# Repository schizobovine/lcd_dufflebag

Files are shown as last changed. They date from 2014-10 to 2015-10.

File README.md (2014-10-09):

lcd_dufflebag
=============

Variation on the common LCD "backpack" design. Instead of using an IO expander or full blown ATMega, however, this design uses an ATTiny84 to drive the LCD, with just enough pins left over to be an I2C slave. Can control RGB LCDs via an optional WS2811 chip or monochrome displays via a simple BJT.

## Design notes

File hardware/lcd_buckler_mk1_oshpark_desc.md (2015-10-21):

Larger 16x2 LCD controller Arduino shield using Yet Another ATTiny84. Reversible. No RGB support.

[https://github.com/schizobovine/lcd_dufflebag](https://github.com/schizobovine/lcd_dufflebag)

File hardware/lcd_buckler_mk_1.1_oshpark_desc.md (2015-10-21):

Revised 8x2 LCD controller Arduino shield using Yet Another ATTiny84. Features solder jumpers to allow host Arduino to program ATTiny84 during development.

[https://github.com/schizobovine/lcd_dufflebag](https://github.com/schizobovine/lcd_dufflebag)

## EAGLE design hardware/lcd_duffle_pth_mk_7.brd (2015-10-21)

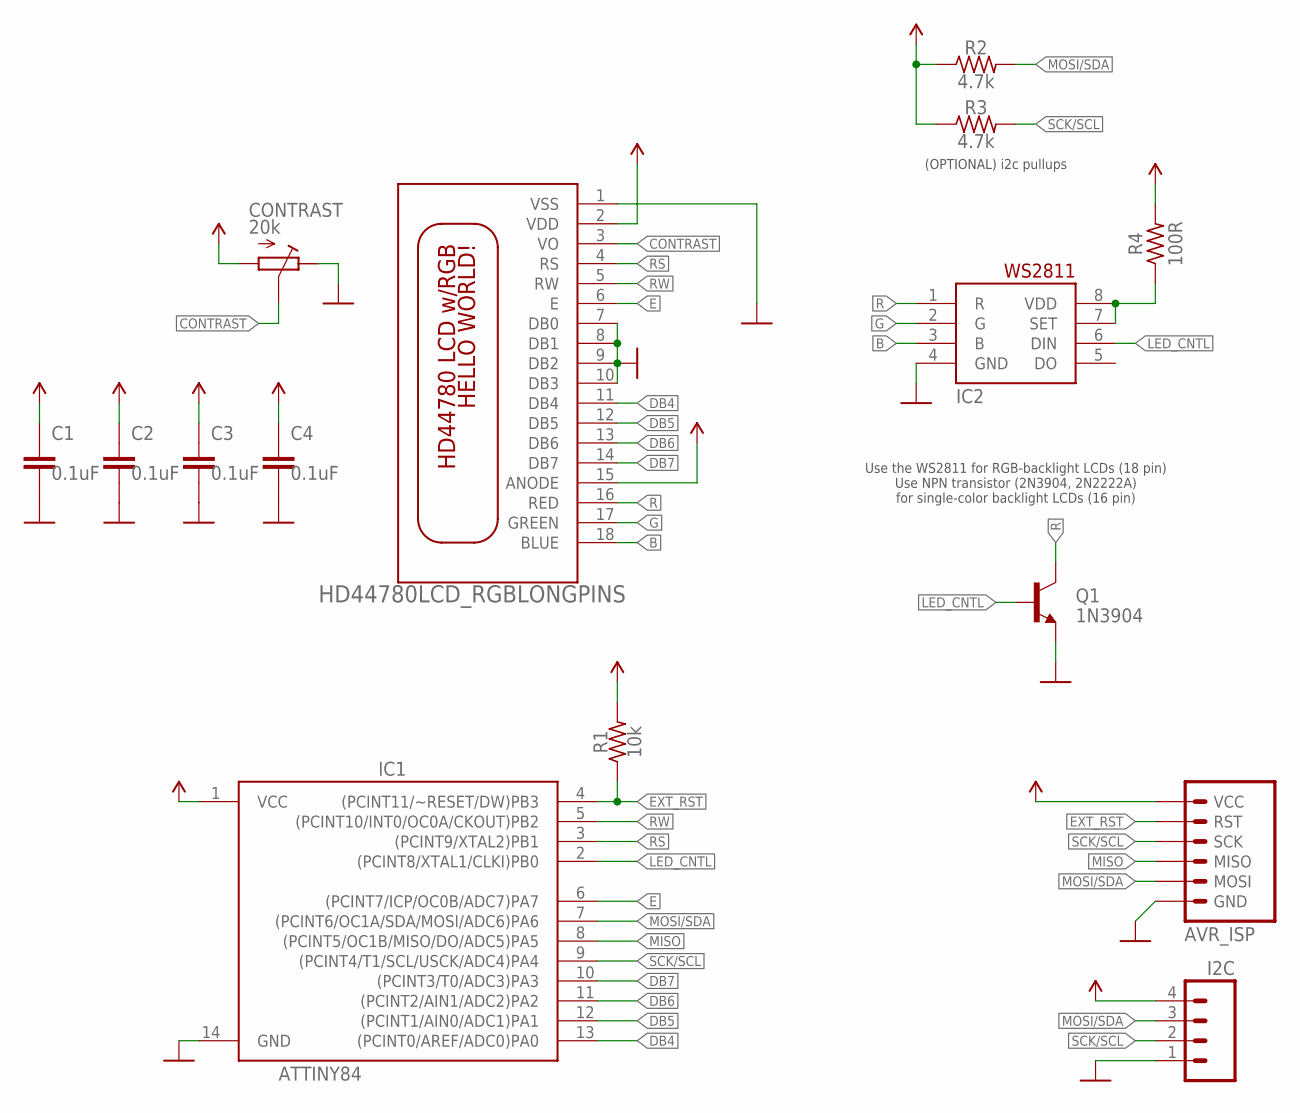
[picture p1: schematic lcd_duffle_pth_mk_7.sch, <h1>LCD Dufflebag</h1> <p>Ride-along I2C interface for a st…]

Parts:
AVR_ISP: AVR_MINI_PROGJST-XH-RA-PTH; AVR_MINI_PROG_JST_XH_RA
C1, C2, C3, C4: 0.1uF; C025-024X044
CONTRAST: 20k; POT-THUMBWHEEL
I2C: M04JST_XH_RA; JST-4-XH-RA-PTH
IC1: ATTINY84; DIL14
IC2: WS2811; SO08-SKINNYPADS
Q1: 1N3904; TO-92-AMMO
R1: 10k; RESISTOR-AXIAL-PTH-5.08MM
R2, R3: 4.7k; RESISTOR-AXIAL-PTH-5.08MM
R4: 100R; RESISTOR-AXIAL-PTH-5.08MM
U$1: HD44780LCD_RGBLONGPINS; LCD1602-RGB-CENTERED

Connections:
5V: AVR_ISP.2 (VCC), C1.2, C2.2, C3.2, C4.2, CONTRAST.1 (A), I2C.4, IC1.1 (VCC), R1.P$2 (2), R2.P$1 (1), R3.P$1 (1), R4.P$2 (2), U$1.2 (VDD), U$1.15 (ANODE)
B: IC2.3 (B), U$1.18 (BLUE)
CONTRAST: CONTRAST.2 (S), CONTRAST.2@1 (S), U$1.3 (VO)
DB4: IC1.13 ((PCINT0/AREF/ADC0)PA0), U$1.11 (DB4)
DB5: IC1.12 ((PCINT1/AIN0/ADC1)PA1), U$1.12 (DB5)
DB6: IC1.11 ((PCINT2/AIN1/ADC2)PA2), U$1.13 (DB6)
DB7: IC1.10 ((PCINT3/T0/ADC3)PA3), U$1.14 (DB7)
E: IC1.6 ((PCINT7/ICP/OC0B/ADC7)PA7), U$1.6 (E)
EXT_RST: AVR_ISP.5 (RST), IC1.4 ((PCINT11/~RESET/DW)PB3), R1.P$1 (1)
G: IC2.2 (G), U$1.17 (GREEN)
GND: AVR_ISP.6 (GND), C1.1, C2.1, C3.1, C4.1, CONTRAST.3 (E), I2C.1, IC1.14 (GND), IC2.4 (GND), Q1.1 (E), U$1.1 (VSS), U$1.7 (DB0), U$1.8 (DB1), U$1.9 (DB2), U$1.10 (DB3)
LED_CNTL: IC1.2 ((PCINT8/XTAL1/CLKI)PB0), IC2.6 (DIN), Q1.2 (B)
MISO: AVR_ISP.1 (MISO), IC1.8 ((PCINT5/OC1B/MISO/DO/ADC5)PA5)
MOSI/SDA: AVR_ISP.4 (MOSI), I2C.3, IC1.7 ((PCINT6/OC1A/SDA/MOSI/ADC6)PA6), R2.P$2 (2)
unnamed: IC2.7 (SET), IC2.8 (VDD), R4.P$1 (1)
R: IC2.1 (R), Q1.3 (C), U$1.16 (RED)
RS: IC1.3 ((PCINT9/XTAL2)PB1), U$1.4 (RS)
RW: IC1.5 ((PCINT10/INT0/OC0A/CKOUT)PB2), U$1.5 (RW)
SCK/SCL: AVR_ISP.3 (SCK), I2C.2, IC1.9 ((PCINT4/T1/SCL/USCK/ADC4)PA4), R3.P$2 (2)

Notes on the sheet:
Use the WS2811 for RGB-backlight LCDs (18 pin) Use NPN transistor (2N3904, 2N2222A) for single-color backlight LCDs (16 pin)
(OPTIONAL) i2c pullups

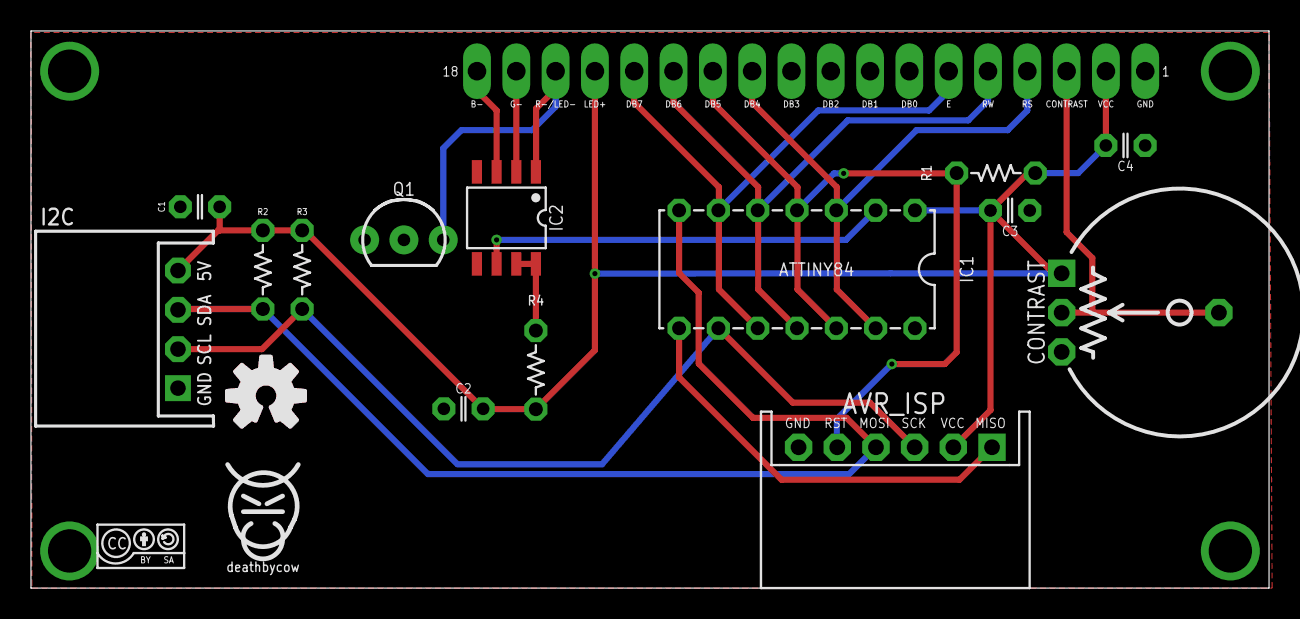
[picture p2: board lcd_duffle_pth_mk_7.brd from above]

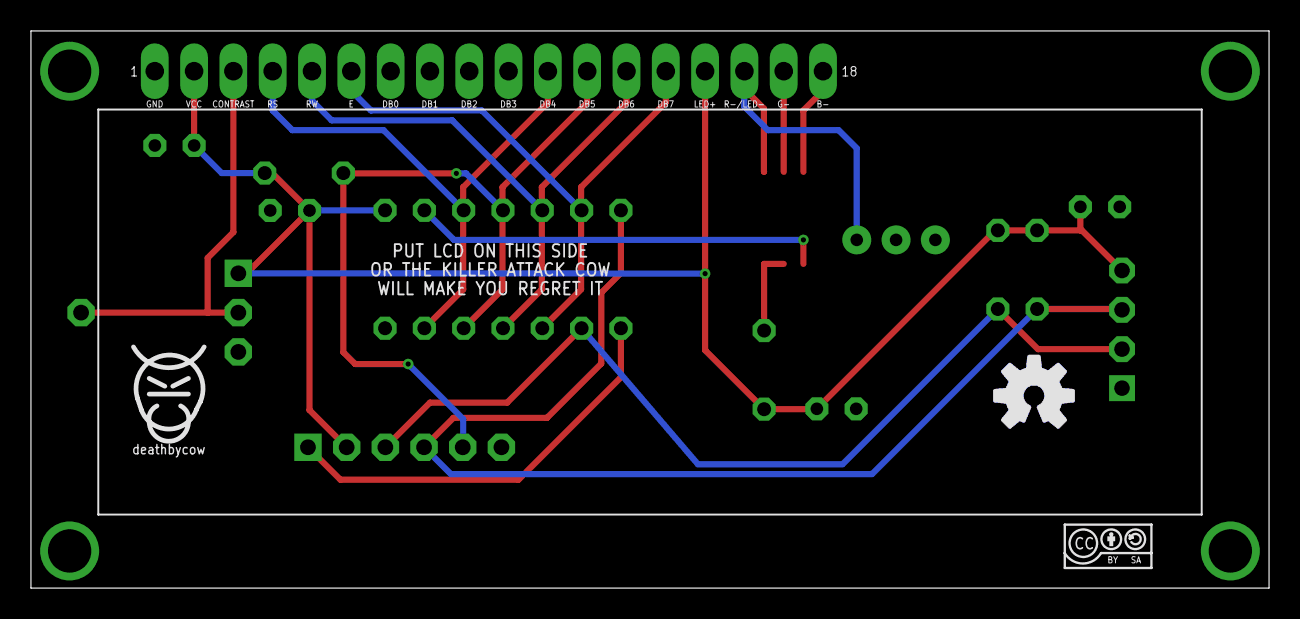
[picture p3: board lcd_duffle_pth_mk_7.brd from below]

Board: 2 copper layers, 80.0 x 36.0 mm, 21 parts (5 on the bottom side), 19 nets.

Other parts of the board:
U$2, U$3: COW_SMALL
U$4, U$6: CC-BY-SA-4.0-NO-URL
U$5: OSHWLOGO_TOP_0.2_A
U$7: OSHWLOGO_BOT_0.2_A

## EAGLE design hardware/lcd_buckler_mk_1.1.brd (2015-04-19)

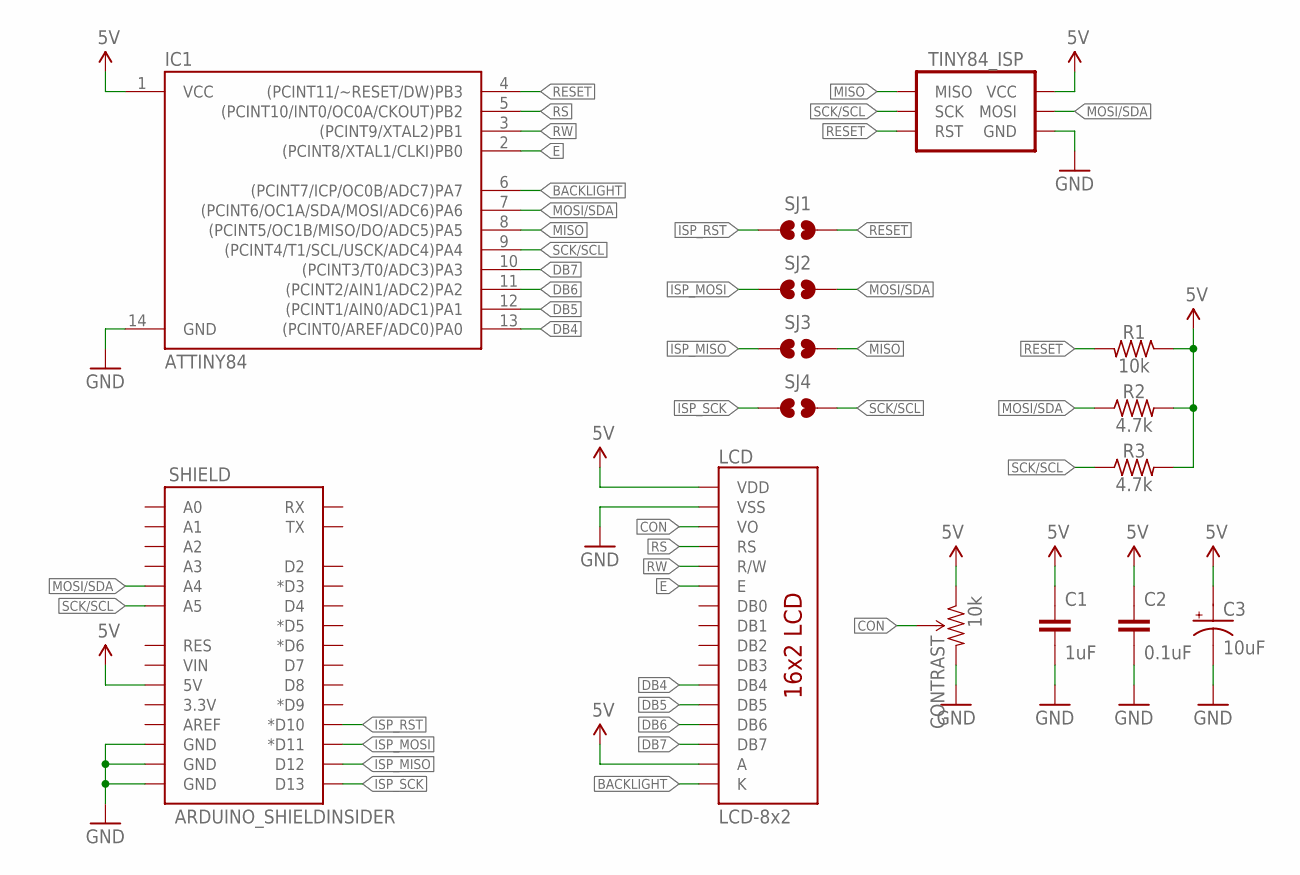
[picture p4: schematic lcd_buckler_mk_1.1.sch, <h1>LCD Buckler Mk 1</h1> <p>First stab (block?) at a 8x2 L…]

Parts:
C1: 1uF; C025-024X044
C2: 0.1uF; C025-024X044
C3: 10uF; E2,5-5
CONTRAST: 10k; TRIM_POT_PTH
IC1: ATTINY84; DIL14
LCD: LCD-8x2; LCD-8X2
R1: 10k; RESISTOR-AXIAL-PTH-7.62MM
R2, R3: 4.7k; RESISTOR-AXIAL-PTH-7.62MM
SHIELD: ARDUINO_SHIELDINSIDER; ARDUINO_SHIELD_NOOUTLINE_INSIDE
SJ1, SJ2, SJ3, SJ4: JUMPER-PAD-2-NO; PAD-JUMPER-2-NO_NO_SILK
TINY84_ISP: AVR_SPI_PRG_6PTH; 2X3

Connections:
5V: C1.1, C2.1, C3.+, CONTRAST.1 (CCW), IC1.1 (VCC), LCD.2 (VDD), LCD.15 (A), R1.P$1 (1), R2.P$2 (2), R3.P$2 (2), SHIELD.5V, TINY84_ISP.2 (VCC)
BACKLIGHT: IC1.6 ((PCINT7/ICP/OC0B/ADC7)PA7), LCD.16 (K)
CON: CONTRAST.2 (WIPER), LCD.3 (VO)
DB4: IC1.13 ((PCINT0/AREF/ADC0)PA0), LCD.11 (DB4)
DB5: IC1.12 ((PCINT1/AIN0/ADC1)PA1), LCD.12 (DB5)
DB6: IC1.11 ((PCINT2/AIN1/ADC2)PA2), LCD.13 (DB6)
DB7: IC1.10 ((PCINT3/T0/ADC3)PA3), LCD.14 (DB7)
E: IC1.2 ((PCINT8/XTAL1/CLKI)PB0), LCD.6 (E)
GND: C1.2, C2.2, C3.-, CONTRAST.3 (CW), IC1.14 (GND), LCD.1 (VSS), SHIELD.GND@0 (GND), SHIELD.GND@1 (GND), SHIELD.GND@2 (GND), TINY84_ISP.6 (GND)
ISP_MISO: SHIELD.D12, SJ3.1
ISP_MOSI: SHIELD.D11 (*D11), SJ2.1
ISP_RST: SHIELD.D10 (*D10), SJ1.1
ISP_SCK: SHIELD.D13, SJ4.1
MISO: IC1.8 ((PCINT5/OC1B/MISO/DO/ADC5)PA5), SJ3.2, TINY84_ISP.1 (MISO)
MOSI/SDA: IC1.7 ((PCINT6/OC1A/SDA/MOSI/ADC6)PA6), R2.P$1 (1), SHIELD.A4, SJ2.2, TINY84_ISP.4 (MOSI)
RESET: IC1.4 ((PCINT11/~RESET/DW)PB3), R1.P$2 (2), SJ1.2, TINY84_ISP.5 (RST)
RS: IC1.5 ((PCINT10/INT0/OC0A/CKOUT)PB2), LCD.4 (RS)
RW: IC1.3 ((PCINT9/XTAL2)PB1), LCD.5 (R/W)
SCK/SCL: IC1.9 ((PCINT4/T1/SCL/USCK/ADC4)PA4), R3.P$1 (1), SHIELD.A5, SJ4.2, TINY84_ISP.3 (SCK)

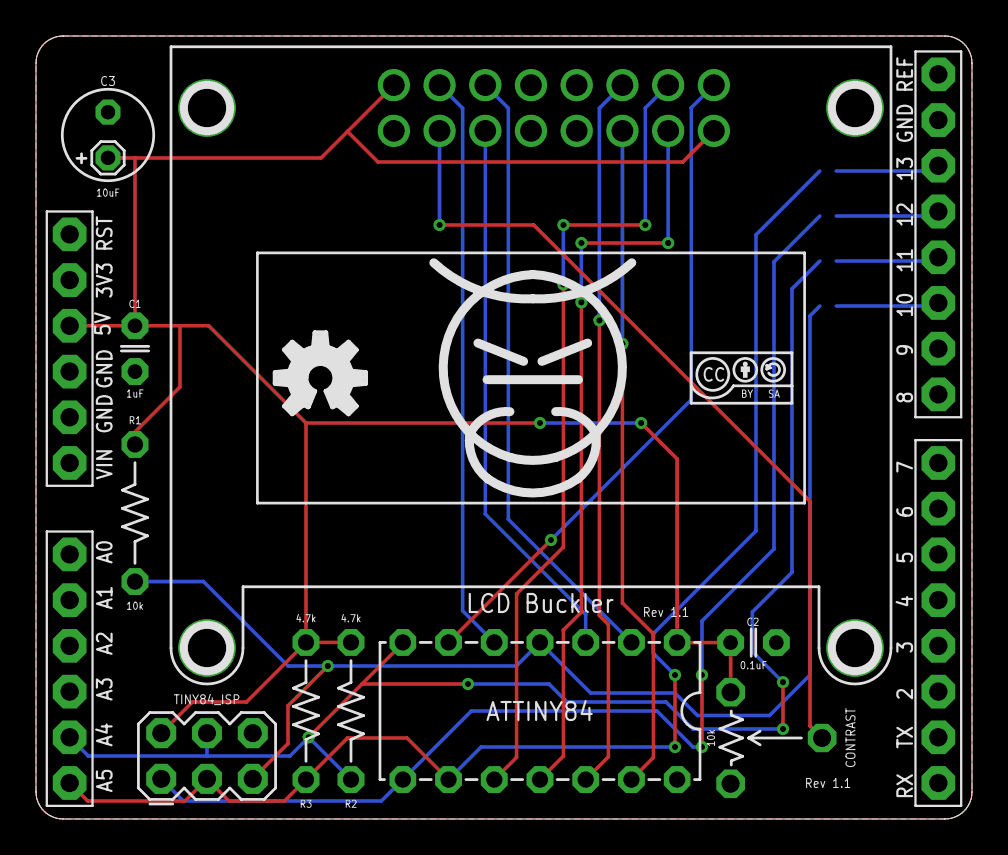
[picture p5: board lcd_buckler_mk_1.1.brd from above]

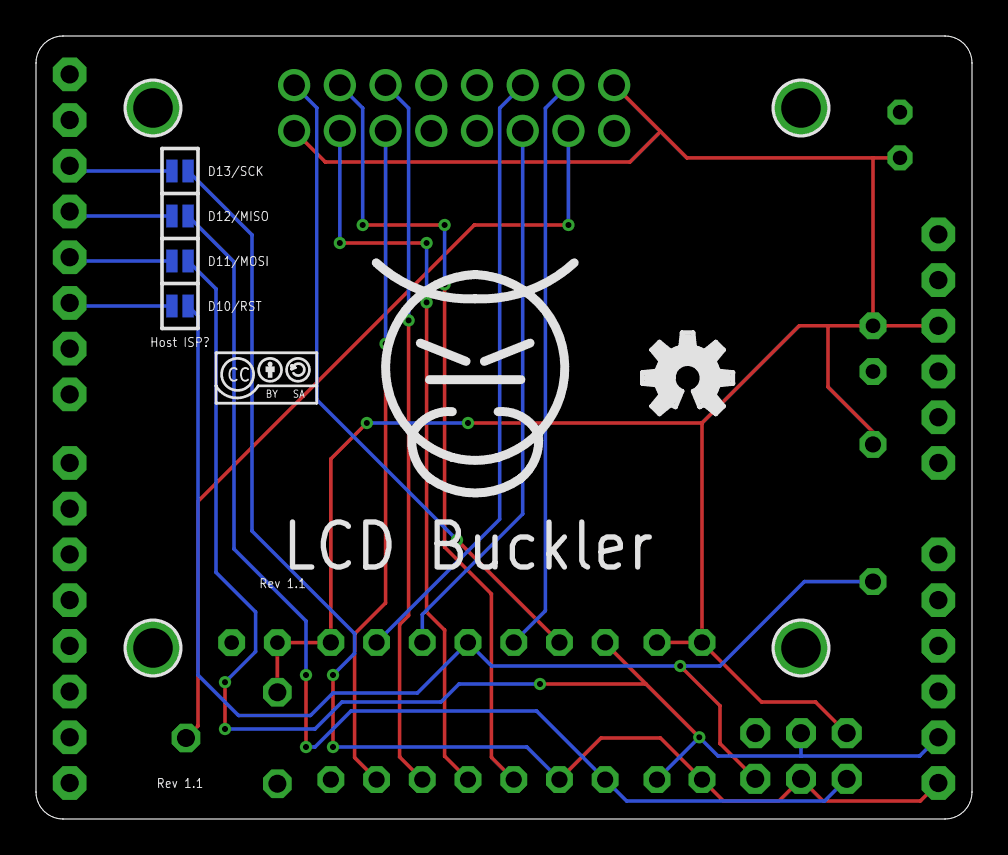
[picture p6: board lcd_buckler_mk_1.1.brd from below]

Board: 2 copper layers, 52.0 x 43.5 mm, 21 parts (7 on the bottom side), 19 nets.

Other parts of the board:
U$1, U$2: COW
U$3, U$4: CC-BY-SA-4.0-NO-URL
U$5, U$6: OSHWLOGO_SILKONLY

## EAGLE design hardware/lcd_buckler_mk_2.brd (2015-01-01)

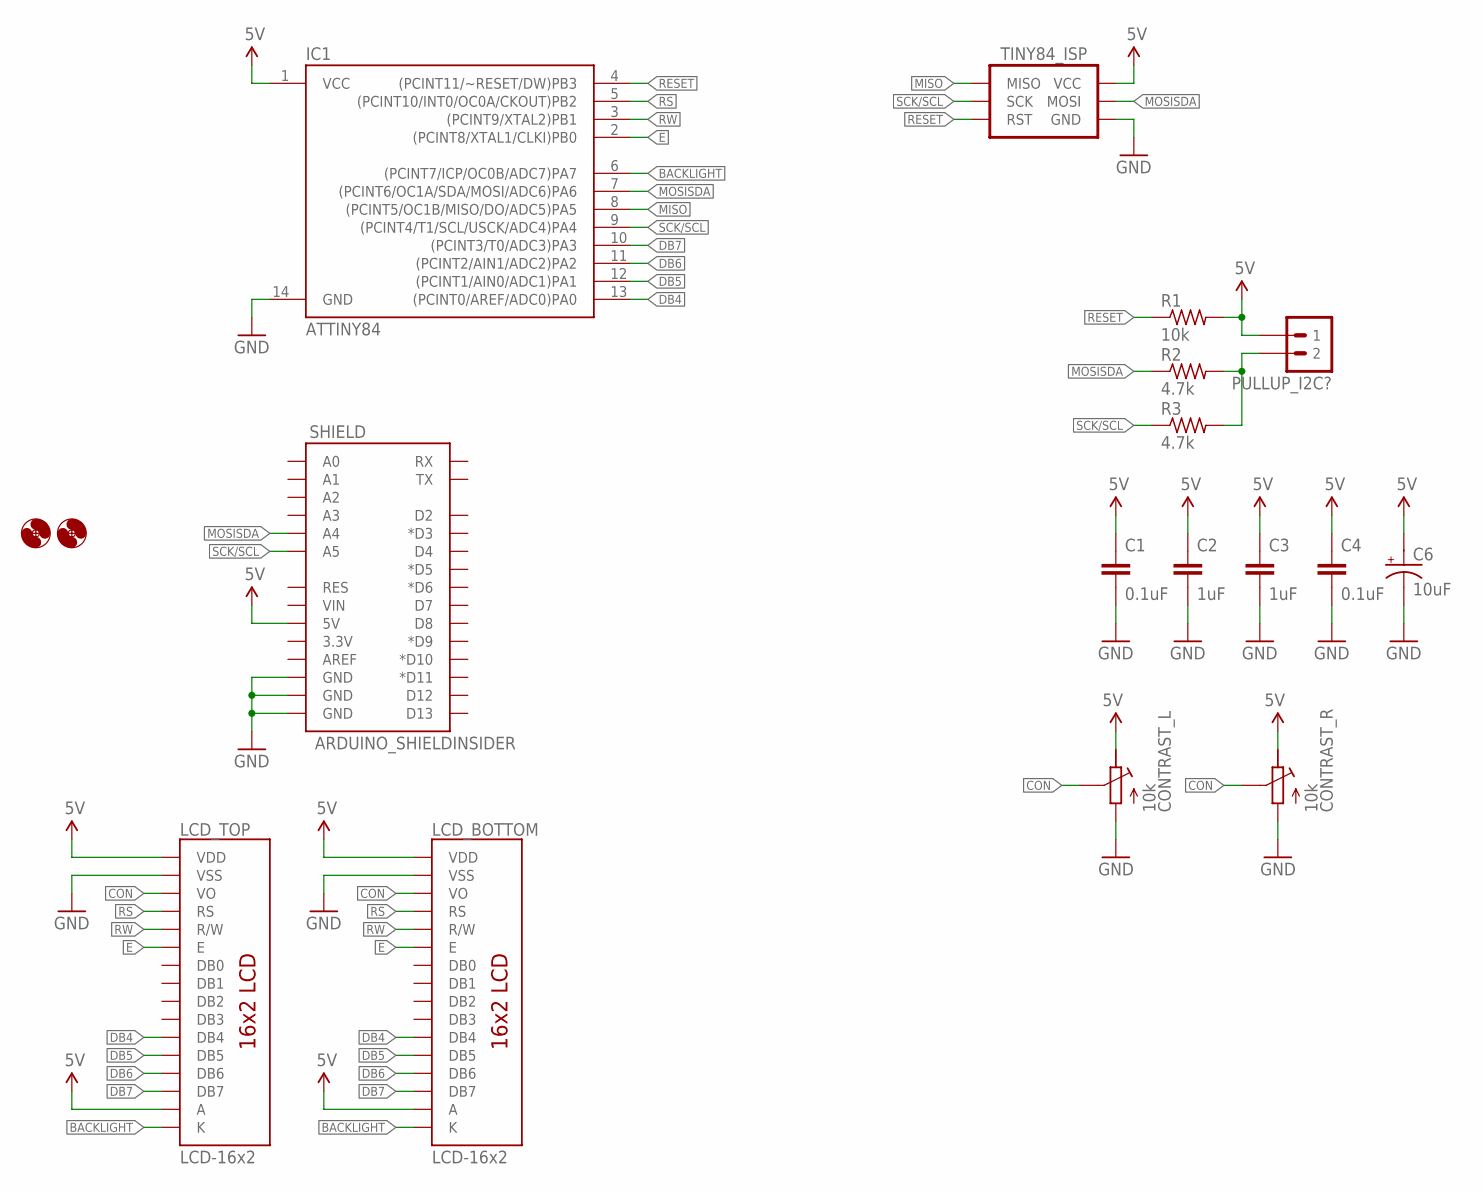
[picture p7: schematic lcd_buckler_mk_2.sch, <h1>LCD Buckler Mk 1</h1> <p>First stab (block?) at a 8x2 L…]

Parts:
C1: 0.1uF; C0805
C2, C3: 1uF; C025-024X044
C4: 0.1uF; C025-024X044
C6: 10uF; E2,5-5
CONTRAST_L: 10k; POT-THUMBWHEEL
CONTRAST_R: 10k; POT-THUMBWHEEL
H1, H2: HOLE#2; HOLE-#2
IC1: ATTINY84; SO14
LCD_BOTTOM: LCD-16x2; LCD-16X2-PINS-ONLY
LCD_TOP: LCD-16x2; LCD-16X2-PINS-ONLY
PULLUP_I2C?: M02PTH; 1X02
R1: 10k; R0805
R2, R3: 4.7k; RESISTOR-AXIAL-PTH-7.68MM
SHIELD: ARDUINO_SHIELDINSIDER; ARDUINO_SHIELD_NOOUTLINE_INSIDE
TINY84_ISP: AVR_SPI_PRG_6PTH; 2X3

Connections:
5V: C1.1, C2.1, C3.1, C4.1, C6.+, CONTRAST_L.3 (E), CONTRAST_R.3 (E), IC1.1 (VCC), LCD_BOTTOM.2 (VDD), LCD_BOTTOM.15 (A), LCD_TOP.2 (VDD), LCD_TOP.15 (A), PULLUP_I2C?.1, R1.2, SHIELD.5V, TINY84_ISP.2 (VCC)
BACKLIGHT: IC1.6 ((PCINT7/ICP/OC0B/ADC7)PA7), LCD_BOTTOM.16 (K), LCD_TOP.16 (K)
CON: CONTRAST_L.2 (S), CONTRAST_L.2@1 (S), CONTRAST_R.2 (S), CONTRAST_R.2@1 (S), LCD_BOTTOM.3 (VO), LCD_TOP.3 (VO)
DB4: IC1.13 ((PCINT0/AREF/ADC0)PA0), LCD_BOTTOM.11 (DB4), LCD_TOP.11 (DB4)
DB5: IC1.12 ((PCINT1/AIN0/ADC1)PA1), LCD_BOTTOM.12 (DB5), LCD_TOP.12 (DB5)
DB6: IC1.11 ((PCINT2/AIN1/ADC2)PA2), LCD_BOTTOM.13 (DB6), LCD_TOP.13 (DB6)
DB7: IC1.10 ((PCINT3/T0/ADC3)PA3), LCD_BOTTOM.14 (DB7), LCD_TOP.14 (DB7)
E: IC1.2 ((PCINT8/XTAL1/CLKI)PB0), LCD_BOTTOM.6 (E), LCD_TOP.6 (E)
GND: C1.2, C2.2, C3.2, C4.2, C6.-, CONTRAST_L.1 (A), CONTRAST_R.1 (A), IC1.14 (GND), LCD_BOTTOM.1 (VSS), LCD_TOP.1 (VSS), SHIELD.GND@0 (GND), SHIELD.GND@1 (GND), SHIELD.GND@2 (GND), TINY84_ISP.6 (GND)
MISO: IC1.8 ((PCINT5/OC1B/MISO/DO/ADC5)PA5), TINY84_ISP.1 (MISO)
MOSISDA: IC1.7 ((PCINT6/OC1A/SDA/MOSI/ADC6)PA6), R2.P$1 (1), SHIELD.A4, TINY84_ISP.4 (MOSI)
unnamed: PULLUP_I2C?.2, R2.P$2 (2), R3.P$2 (2)
RESET: IC1.4 ((PCINT11/~RESET/DW)PB3), R1.1, TINY84_ISP.5 (RST)
RS: IC1.5 ((PCINT10/INT0/OC0A/CKOUT)PB2), LCD_BOTTOM.4 (RS), LCD_TOP.4 (RS)
RW: IC1.3 ((PCINT9/XTAL2)PB1), LCD_BOTTOM.5 (R/W), LCD_TOP.5 (R/W)
SCK/SCL: IC1.9 ((PCINT4/T1/SCL/USCK/ADC4)PA4), R3.P$1 (1), SHIELD.A5, TINY84_ISP.3 (SCK)

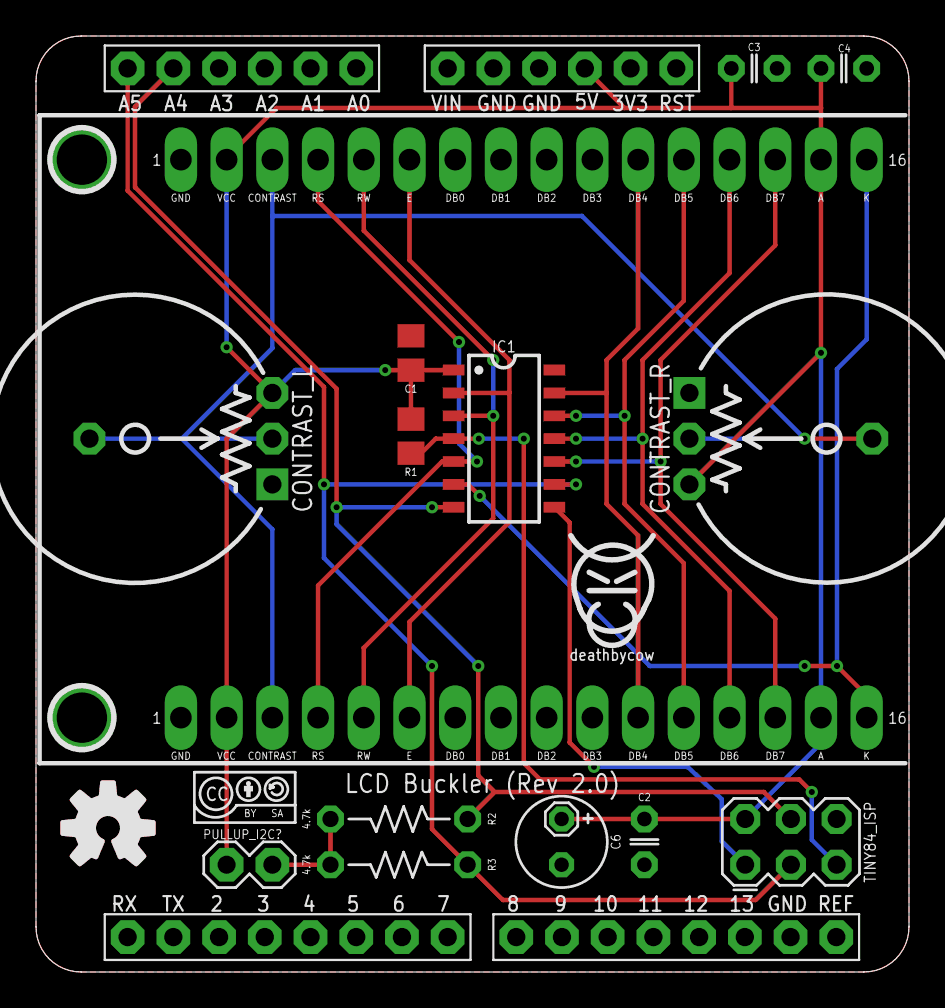
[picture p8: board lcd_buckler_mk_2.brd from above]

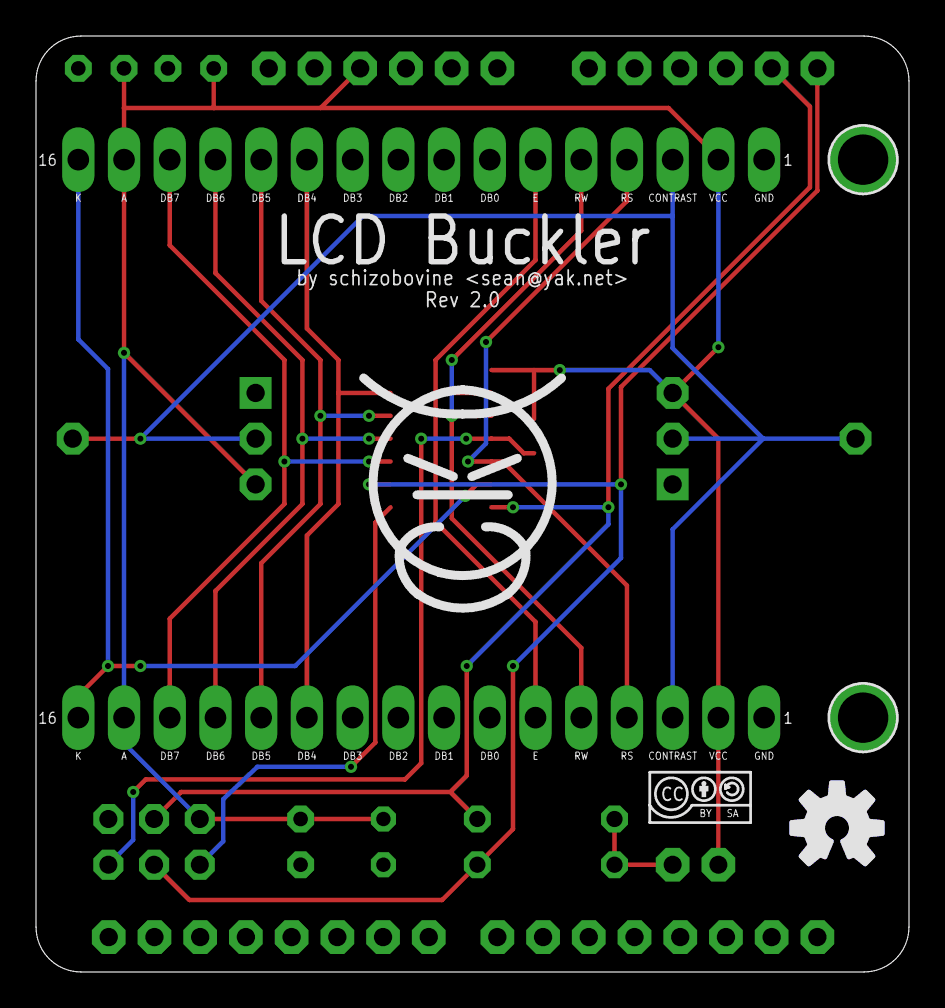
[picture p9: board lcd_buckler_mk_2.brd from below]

Board: 2 copper layers, 48.5 x 52.0 mm, 24 parts (2 on the bottom side), 16 nets.

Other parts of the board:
U$1: COW
U$2: COW_SMALL
U$3, U$4: CC-BY-SA-4.0-NO-URL
U$5: OSHWLOGO_TOP_0.2_A
U$6: OSHWLOGO_BOT_0.2_A

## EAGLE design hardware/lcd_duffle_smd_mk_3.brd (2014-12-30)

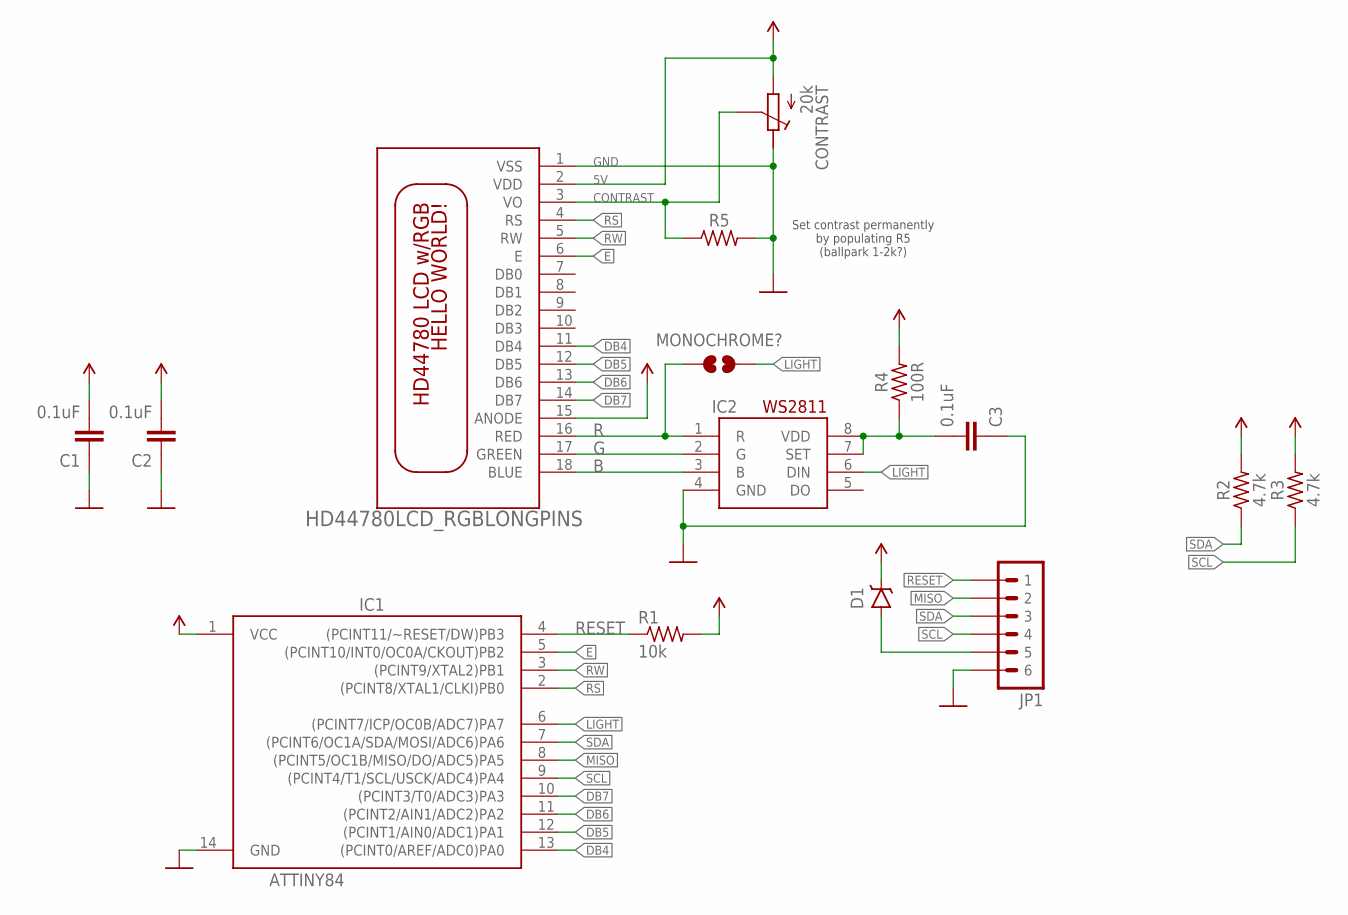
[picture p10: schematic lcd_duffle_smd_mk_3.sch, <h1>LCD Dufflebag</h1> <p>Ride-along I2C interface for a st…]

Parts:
C1, C2, C3: 0.1uF; C0805
CONTRAST: 20k; RTRIM3314Z-SIDE
D1: MBRA140; SMA-DIODE
IC1: ATTINY84; SO14
IC2: WS2811; SO08-SKINNYPADS
JP1: M06SMD; 1X06-SMD
MONOCHROME?: JUMPER-PAD-2-NOYES_SILK; PAD-JUMPER-2-NO_YES_SILK
R1: 10k; R0805
R2, R3: 4.7k; R0805
R4: 100R; R0805
R5: RESISTORR0805; R0805
U$1: HD44780LCD_RGBLONGPINS; LCD1602-RGB-CENTERED

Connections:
5V: C1.2, C2.2, CONTRAST.1 (A), D1.C, IC1.1 (VCC), R1.2, R2.2, R3.2, R4.2, U$1.2 (VDD), U$1.15 (ANODE)
B: IC2.3 (B), U$1.18 (BLUE)
CONTRAST: CONTRAST.2 (S), R5.1, U$1.3 (VO)
DB4: IC1.13 ((PCINT0/AREF/ADC0)PA0), U$1.11 (DB4)
DB5: IC1.12 ((PCINT1/AIN0/ADC1)PA1), U$1.12 (DB5)
DB6: IC1.11 ((PCINT2/AIN1/ADC2)PA2), U$1.13 (DB6)
DB7: IC1.10 ((PCINT3/T0/ADC3)PA3), U$1.14 (DB7)
E: IC1.5 ((PCINT10/INT0/OC0A/CKOUT)PB2), U$1.6 (E)
G: IC2.2 (G), U$1.17 (GREEN)
GND: C1.1, C2.1, C3.1, CONTRAST.3 (E), IC1.14 (GND), IC2.4 (GND), JP1.6, R5.2, U$1.1 (VSS)
LIGHT: IC1.6 ((PCINT7/ICP/OC0B/ADC7)PA7), IC2.6 (DIN), MONOCHROME?.2
MISO: IC1.8 ((PCINT5/OC1B/MISO/DO/ADC5)PA5), JP1.2
unnamed: D1.A, JP1.5
unnamed: C3.2, IC2.7 (SET), IC2.8 (VDD), R4.1
R: IC2.1 (R), MONOCHROME?.1, U$1.16 (RED)
RESET: IC1.4 ((PCINT11/~RESET/DW)PB3), JP1.1, R1.1
RS: IC1.2 ((PCINT8/XTAL1/CLKI)PB0), U$1.4 (RS)
RW: IC1.3 ((PCINT9/XTAL2)PB1), U$1.5 (RW)
SCL: IC1.9 ((PCINT4/T1/SCL/USCK/ADC4)PA4), JP1.4, R3.1
SDA: IC1.7 ((PCINT6/OC1A/SDA/MOSI/ADC6)PA6), JP1.3, R2.1

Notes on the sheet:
Set contrast permanently by populating R5 (ballpark 1-2k?)

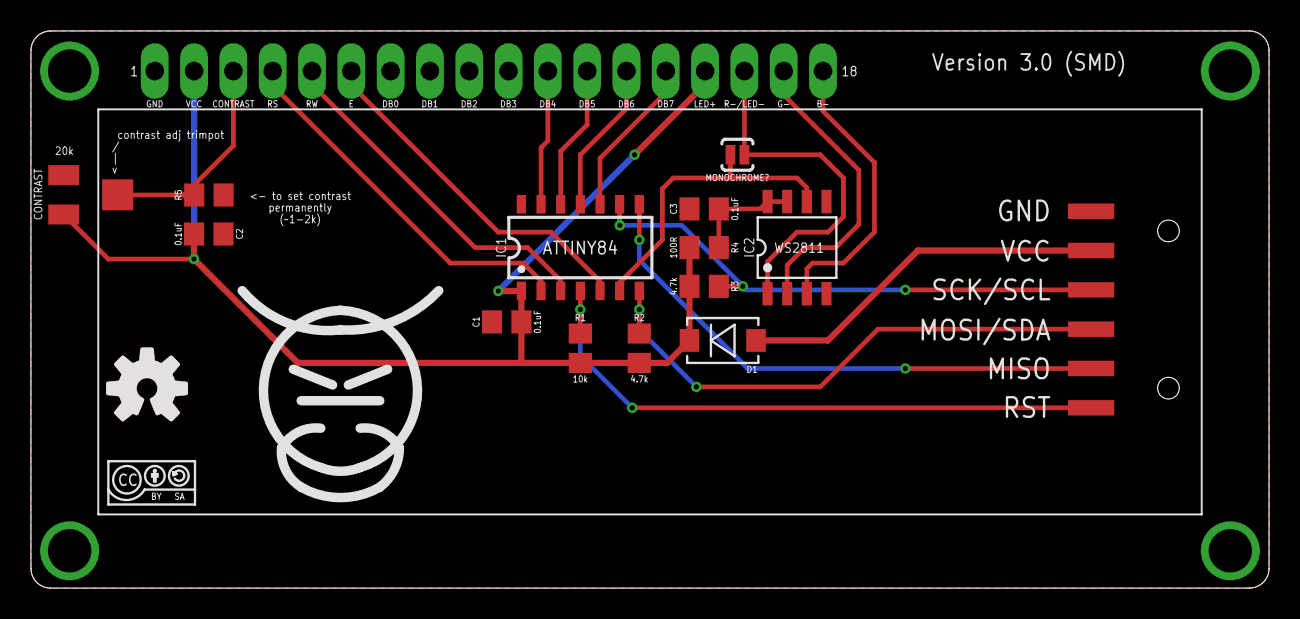
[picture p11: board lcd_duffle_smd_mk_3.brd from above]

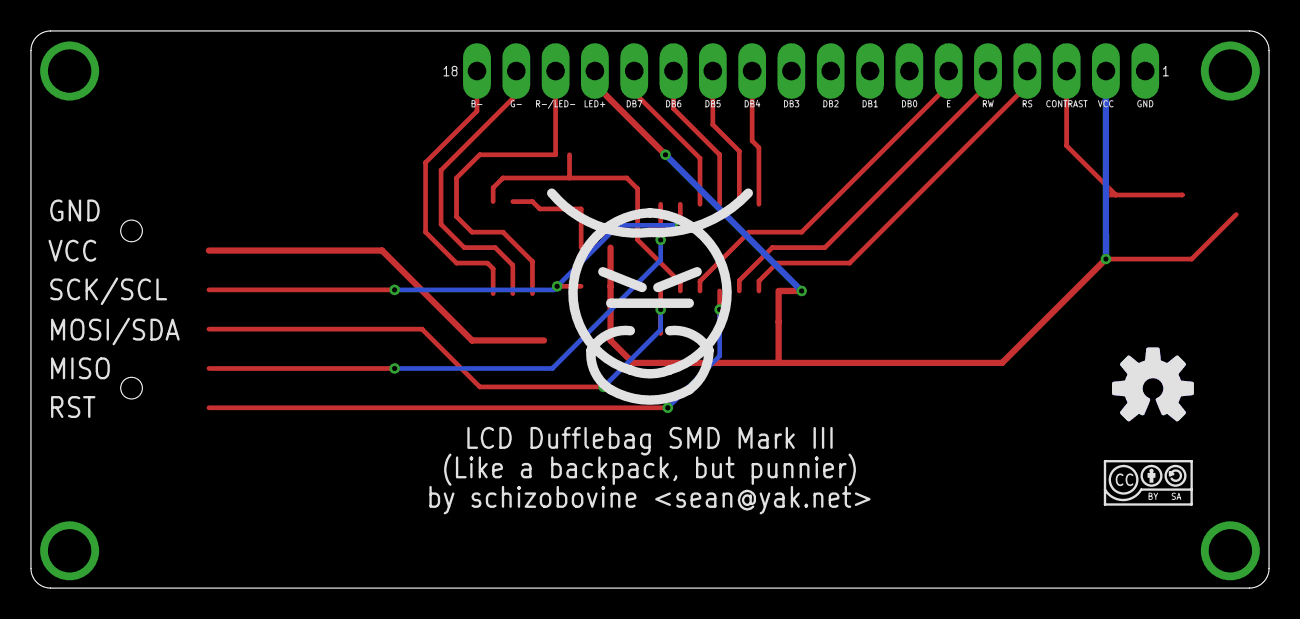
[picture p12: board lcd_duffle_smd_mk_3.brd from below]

Board: 2 copper layers, 80.0 x 36.0 mm, 21 parts (2 on the bottom side), 20 nets.

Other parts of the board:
U$2, U$3: COW
U$4, U$5: CC-BY-SA-4.0-NO-URL
U$6: OSHWLOGO_TOP_0.2_A
U$7: OSHWLOGO_BOT_0.2_A

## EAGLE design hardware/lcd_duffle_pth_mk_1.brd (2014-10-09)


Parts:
ATTINY84: ATTINY84ATTINY84-20PU; DIL14
C1, C2, C3, C4: 0.1uF; C025-024X044
CONTRAST: TRIMPOT3362U-2; 3362U-2
ICSP: AVR_SPI_PRG_6PTH; 2X3
JP1: I2C; MOLEX-1X4
JP2: I2C; 1X04-BIG
Q1: 2N3904; TO-92-AMMO
R1: 10k; AXIAL-PTH-5.08MM
R3: 33R; AXIAL-PTH-5.08MM
R4: 100R; AXIAL-PTH-5.08MM
U$1: HD44780LCD_RGBLONGPINS; LCD1602-RGB
WS2811: WS2811-SOP8; SO08-SKINNYPADS

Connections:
5V: ATTINY84.1 (VCC), C2.2, C3.2, C4.2, CONTRAST.3 (CW), ICSP.2, JP1.4, JP2.4, Q1.3 (C), R1.P$1 (2), R4.P$1 (2), U$1.2 (VDD)
B: U$1.18 (BLUE), WS2811.3 (B)
BL_EN: ATTINY84.8 ((PCINT5/OC1B/MISO/DO/ADC5)PA5), ICSP.1, Q1.2 (B)
CONTRAST: CONTRAST.2 (WIPER), U$1.3 (VO)
DB4: ATTINY84.10 ((PCINT3/T0/ADC3)PA3), U$1.11 (DB4)
DB5: ATTINY84.11 ((PCINT2/AIN1/ADC2)PA2), U$1.12 (DB5)
DB6: ATTINY84.12 ((PCINT1/AIN0/ADC1)PA1), U$1.13 (DB6)
DB7: ATTINY84.13 ((PCINT0/AREF/ADC0)PA0), U$1.14 (DB7)
E: ATTINY84.6 ((PCINT7/ICP/OC0B/ADC7)PA7), U$1.6 (E)
G: U$1.17 (GREEN), WS2811.2 (G)
GND: ATTINY84.14 (GND), C2.1, C3.1, C4.1, CONTRAST.1 (CCW), ICSP.6, JP1.1, JP2.1, U$1.1 (VSS), WS2811.4 (GND)
LED_CNTL: ATTINY84.5 ((PCINT10/INT0/OC0A/CKOUT)PB2), R3.P$1 (2)
unnamed: R3.P$2 (1), WS2811.6 (DIN)
unnamed: R4.P$2 (1), WS2811.7 (SET), WS2811.8 (VDD)
unnamed: C1.1, ICSP.5
unnamed: Q1.1 (E), U$1.15 (ANODE)
R: U$1.16 (RED), WS2811.1 (R)
RS: ATTINY84.3 ((PCINT9/XTAL2)PB1), U$1.4 (RS)
RST: ATTINY84.4 ((PCINT11/~RESET/DW)PB3), C1.2, R1.P$2 (1)
RW: ATTINY84.2 ((PCINT8/XTAL1/CLKI)PB0), U$1.5 (RW)
SCL: ATTINY84.9 ((PCINT4/T1/SCL/USCK/ADC4)PA4), ICSP.3, JP1.2, JP2.2
SDA: ATTINY84.7 ((PCINT6/OC1A/SDA/MOSI/ADC6)PA6), ICSP.4, JP1.3, JP2.3


Board: 2 copper layers, 80.0 x 36.2 mm, 15 parts (1 on the bottom side), 22 nets.

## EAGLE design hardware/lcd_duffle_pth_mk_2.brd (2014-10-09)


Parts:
ATTINY84: ATTINY84; SO14
C1, C2, C3, C4: 0.1uF; C025-024X044
CONTRAST: POTENTIOMETERTHUMBWHEEL-16MM; POT-THUMBWHEEL
ICSP: M03X2POGO_PINS; 2X3_POGO
JP1: I2C; 1X04-2.5MM_JST_XH_RA
R1: 10k; RESISTOR-AXIAL-PTH-5.08MM
R3: 33R; RESISTOR-AXIAL-PTH-5.08MM
R4: 100R; RESISTOR-AXIAL-PTH-5.08MM
U$1: HD44780LCD_RGBLONGPINS; LCD1602-RGB-CENTERED
WS2811: WS2811-SOP8; SO08-SKINNYPADS

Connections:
5V: ATTINY84.1 (VCC), C2.2, C3.2, C4.2, CONTRAST.1 (A), ICSP.P$2 (2), JP1.4, R1.P$2 (2), R4.P$2 (2), U$1.2 (VDD), U$1.15 (ANODE)
B: U$1.18 (BLUE), WS2811.3 (B)
CONTRAST: CONTRAST.2 (S), CONTRAST.2@1 (S), U$1.3 (VO)
DB4: ATTINY84.13 ((PCINT0/AREF/ADC0)PA0), U$1.11 (DB4)
DB5: ATTINY84.12 ((PCINT1/AIN0/ADC1)PA1), U$1.12 (DB5)
DB6: ATTINY84.11 ((PCINT2/AIN1/ADC2)PA2), U$1.13 (DB6)
DB7: ATTINY84.10 ((PCINT3/T0/ADC3)PA3), U$1.14 (DB7)
E: ATTINY84.8 ((PCINT5/OC1B/MISO/DO/ADC5)PA5), ICSP.P$1 (1), U$1.6 (E)
G: U$1.17 (GREEN), WS2811.2 (G)
GND: ATTINY84.14 (GND), C2.1, C3.1, C4.1, CONTRAST.3 (E), ICSP.P$6 (6), JP1.1, U$1.1 (VSS), U$1.7 (DB0), U$1.8 (DB1), U$1.9 (DB2), U$1.10 (DB3), WS2811.4 (GND)
LED_CNTL: ATTINY84.5 ((PCINT10/INT0/OC0A/CKOUT)PB2), R3.P$2 (2)
unnamed: R3.P$1 (1), WS2811.6 (DIN)
unnamed: R4.P$1 (1), WS2811.7 (SET), WS2811.8 (VDD)
unnamed: C1.1, ICSP.P$5 (5)
R: U$1.16 (RED), WS2811.1 (R)
RS: ATTINY84.3 ((PCINT9/XTAL2)PB1), U$1.4 (RS)
RST: ATTINY84.4 ((PCINT11/~RESET/DW)PB3), C1.2, R1.P$1 (1)
RW: ATTINY84.6 ((PCINT7/ICP/OC0B/ADC7)PA7), U$1.5 (RW)
SCL: ATTINY84.9 ((PCINT4/T1/SCL/USCK/ADC4)PA4), ICSP.P$3 (3), JP1.2
SDA: ATTINY84.7 ((PCINT6/OC1A/SDA/MOSI/ADC6)PA6), ICSP.P$4 (4), JP1.3

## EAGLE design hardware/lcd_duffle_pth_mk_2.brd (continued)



Board: 2 copper layers, 80.0 x 36.0 mm, 17 parts (4 on the bottom side), 20 nets.

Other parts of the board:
U$2, U$3: COW_SMALL
U$5: OSHWLOGO_TOP_0.2_A
U$7: OSHWLOGO_BOT_0.2_A

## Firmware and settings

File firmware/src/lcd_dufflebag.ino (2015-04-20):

/*
 * lcd_dufflebag.h
 */

#include <Arduino.h>
#include <EEPROM.h>
#include <LiquidCrystal.h>
#include <SoftwareSerial.h>
#include "lcd_dufflebag.h"

byte brightness = 0x7f;

SoftwareSerial nouart(RX, TX);
LiquidCrystal lcd = LiquidCrystal(RS, RW, E, DB4, DB5, DB6, DB7);

void display_setup() {

  pinMode(BACKLIGHT, OUTPUT);
  analogWrite(BACKLIGHT, brightness);

  lcd.begin(COLS, ROWS);
  lcd.print("DICKBUTT");
  delay(300);
  lcd.clear();

}

void cmd_clear() {
  lcd.clear();
}

void cmd_home() {
  lcd.home();
}

void cmd_reset() {
  display_setup();
}

void setup() {

  display_setup();

  nouart.begin(9600);

}

void loop() {
  
  // Poll for new data
  if (nouart.available()) {
    byte c = nouart.read();

    // Check for and handle magical command bytes. Should make this a proper
    // state machine.
    if (c >= UART_CMD_MIN) {
      switch (c) {
        case UART_CMD_HOME:
          break;
        case UART_CMD_CLEAR:
          break;
        case UART_CMD_RESET:
          break;
        default:
          break;
      }

    // Default is to write a character to the display
    } else {
      lcd.write(c);
    }

  }

}

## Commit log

2014-10-09 initial commit of work so far
    [lcd_duffle_pth_mk_1.brd, lcd_duffle_pth_mk_1.sch, lcd_duffle_pth_mk_2.brd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]
2014-10-09 mark 5: more bugfixes
    [lcd_duffle_pth_mk_5.brd, lcd_duffle_pth_mk_5.sch]
2014-10-09 revised board to add i2c pullups, relayout to reduce vias since most were due to poor planning, and remove cap from external reset line as it shouldn't be needed according to atmel's docs
    [lcd_duffle_pth_mk_5.brd, lcd_duffle_pth_mk_5.sch]
2014-10-11 prelim version using attiny861
    [lcd_duffle_pth_mk_6.sch]
2014-12-15 updating libs
    [lcd_duffle_smd_mk_2.brd, lcd_duffle_smd_mk_2.sch]
2014-12-15 firmware isn't working, but committing anyway; new smd version that will be on the LCD side to minimize exposed area
    [lcd_duffle_smd_mk_3.brd, lcd_duffle_smd_mk_3.sch]
2014-12-16 ready for the fab
    [lcd_duffle_smd_mk_3.brd, lcd_duffle_smd_mk_3.sch]
2014-12-16 minor tweaks to stop overlapping silkscreen
    [lcd_duffle_smd_mk_3.brd, lcd_duffle_smd_mk_3.sch]
2014-12-16 adding description to board to see if oshpark picks it up
    [lcd_duffle_smd_mk_3.brd]
2014-12-30 LCD i2c interface shield for arduino based on attiny84. if i can ever get it to work, anyway.
    [lcd_buckler_mk_1.brd, lcd_buckler_mk_1.sch]
2014-12-30 fuck if i know what changed
    [lcd_duffle_smd_mk_3.brd]
2014-12-31 added description
    [lcd_buckler_mk_1.sch]
2014-12-31 mark 2 for 16x2 displays
    [lcd_buckler_mk_2.brd, lcd_buckler_mk_2.sch]
2015-01-01 version 2 ready for fab. added lcd connections and trimpots to both sides in case i need to reverse/flip something. disconnect for i2c pull-ups as i'm wondering if those are causing problems.
    [lcd_buckler_mk_2.brd, lcd_buckler_mk_2.sch]
2015-02-13 updates for the update throne
    [lcd_buckler_mk_1.brd, lcd_buckler_mk_1.sch]
2015-04-19 new revision with a few tweaks learned from first
    [lcd_buckler_mk_1.1.brd, lcd_buckler_mk_1.1.sch]

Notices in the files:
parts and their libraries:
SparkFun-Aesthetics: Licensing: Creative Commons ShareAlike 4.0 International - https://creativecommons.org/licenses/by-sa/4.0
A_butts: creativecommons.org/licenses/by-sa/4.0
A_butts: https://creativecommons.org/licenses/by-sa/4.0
